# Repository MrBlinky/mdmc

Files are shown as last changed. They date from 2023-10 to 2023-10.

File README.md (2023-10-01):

# MDMC - Menu Driven Multi Cart

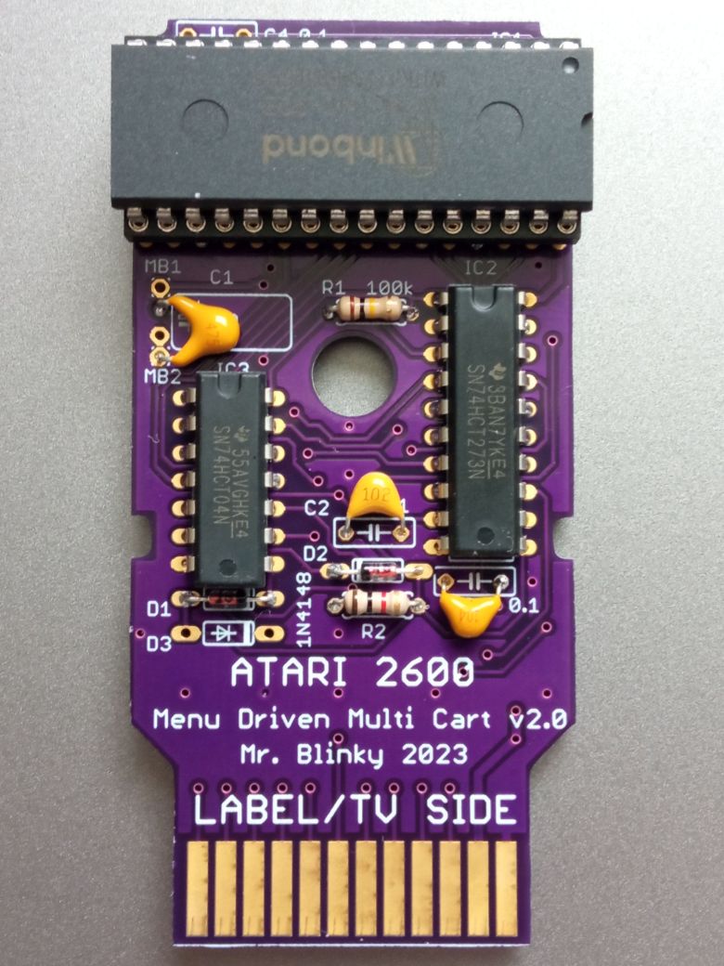
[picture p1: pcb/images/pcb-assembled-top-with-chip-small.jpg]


A Menu driven Multi Cart for the Atari 2600 made out of a few descrete logic chips and a (E)EPROM or FLASH memory.

Boards can be ordered from [OSH Park](https://oshpark.com/shared_projects/qgWffwwL) or you can create your own using the Eagle board file.

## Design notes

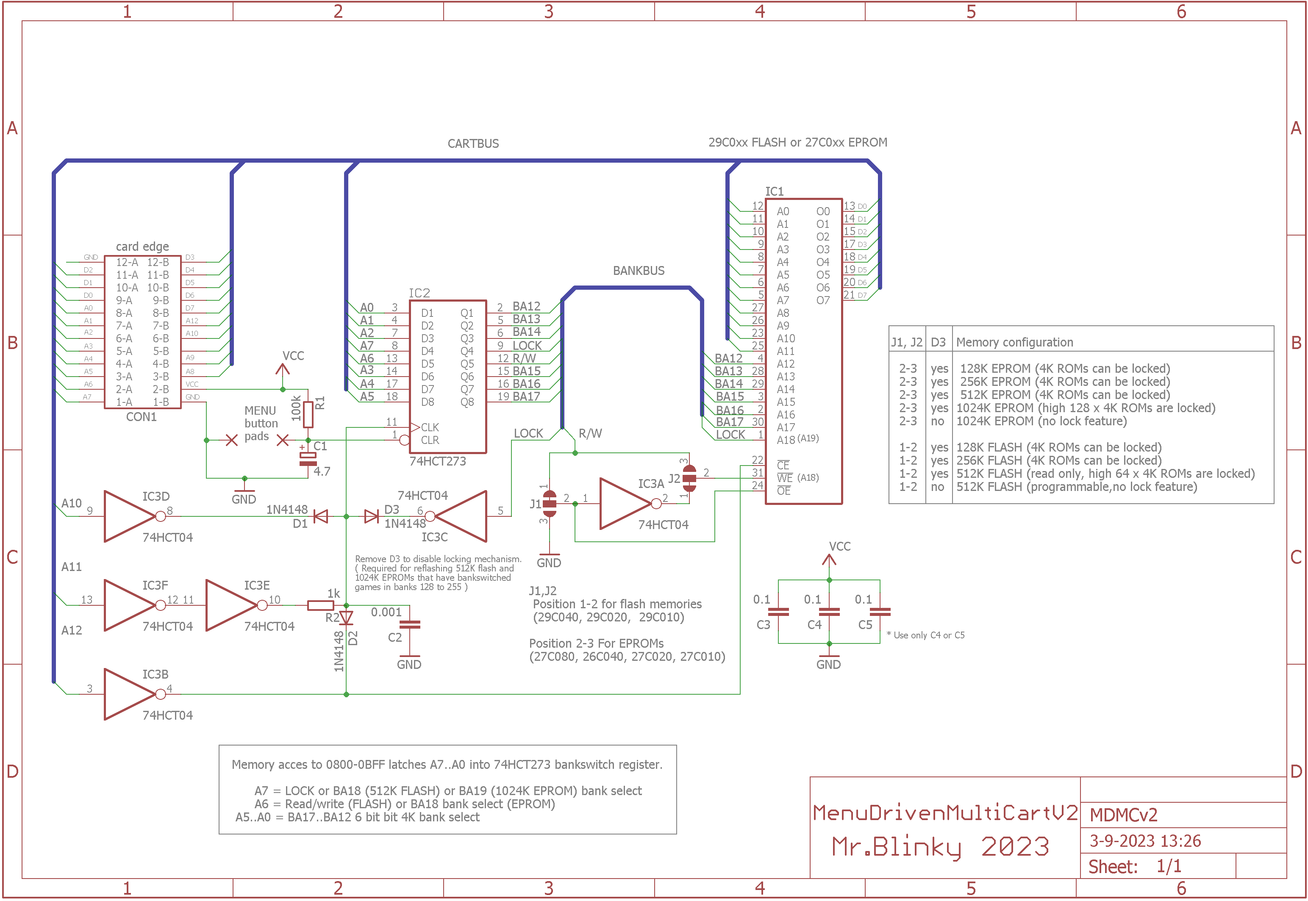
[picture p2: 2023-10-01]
pcb/eagle/MDMCv2-schematic.png

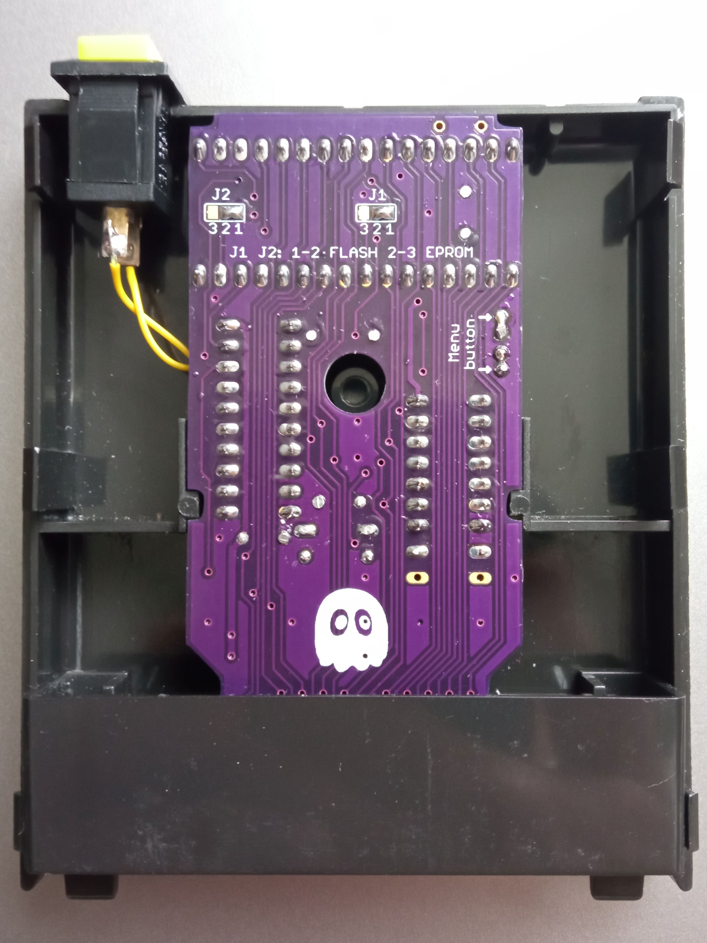
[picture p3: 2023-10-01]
pcb/images/pcb-inside-cart-with-switch.jpg

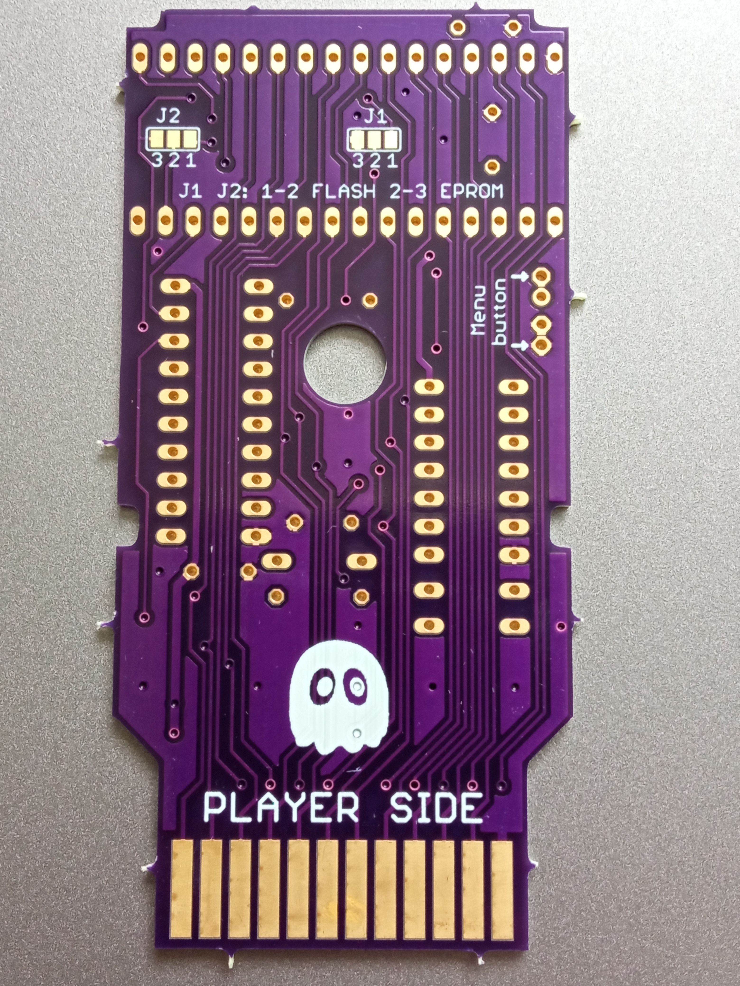
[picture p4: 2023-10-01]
pcb/images/pcb-raw-bottom.jpg

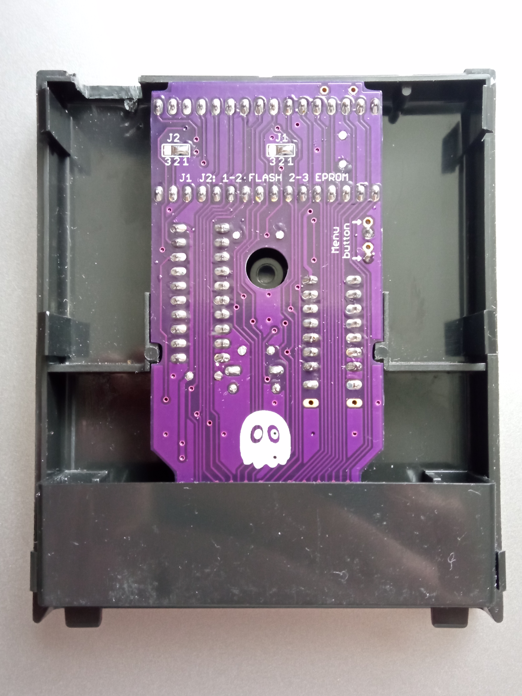
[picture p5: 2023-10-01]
pcb/images/pcb-inside-cart.jpg

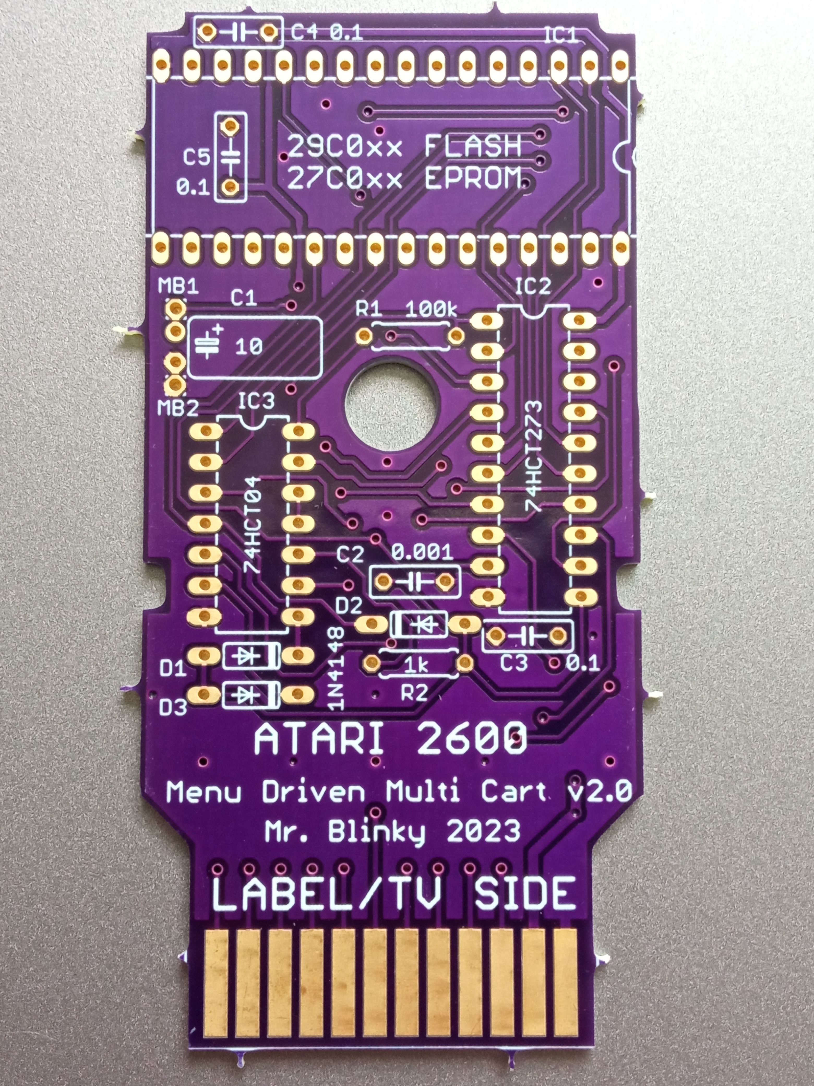
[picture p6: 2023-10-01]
pcb/images/pcb-raw-top.jpg

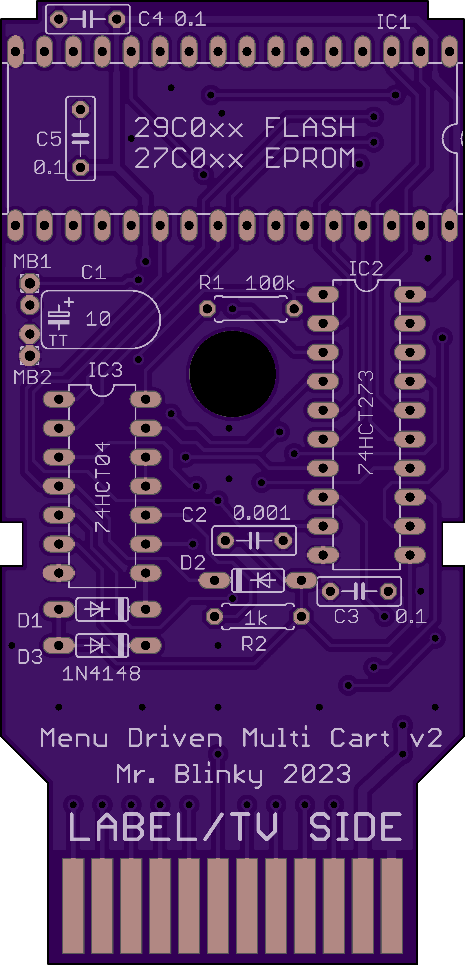
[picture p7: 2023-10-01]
pcb/images/pcb-oshpark-render-top.png

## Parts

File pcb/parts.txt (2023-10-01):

-----------------
MDMC v2 part list
-----------------

R1 = 100 kOhm
R2 = 1 kOhm

C1 = 4,7 uF (alternatives 1uF or 10uF)
C2 = 1 nF
C3, C4*, C5* = 100 nF

D1, D2, D3** = 1N4148

IC1 = EEPROM: 27C080, 27C040, 27C020, 27C010 or FLASH: 29C040, 29C020, 29C010
IC2 = 74HCT273 (alternatives 74HC273, 74LS273)
IC3 = 74HCT04 (alternatives  74HC04, 74LS04)

Optional:

32 pin IC socket
Garyma DS-429 momentary push button (for return to menu feature)

Notes:

*  Only solder C4 or C5.
   When soldering the EEPROM/FLASH chip directly on to the PCB, solder C4.
   When using an IC socket, solder C5.
   
** D3 required when bank locking feature is wanted for 4K roms that accidently may trigger bankswitch hotspots.
   D3 should not be used when bankswitch games are present in upper 512K of a 1MEG EPROM.
   D3 should not be used for 512K reprogrammable flash cart.

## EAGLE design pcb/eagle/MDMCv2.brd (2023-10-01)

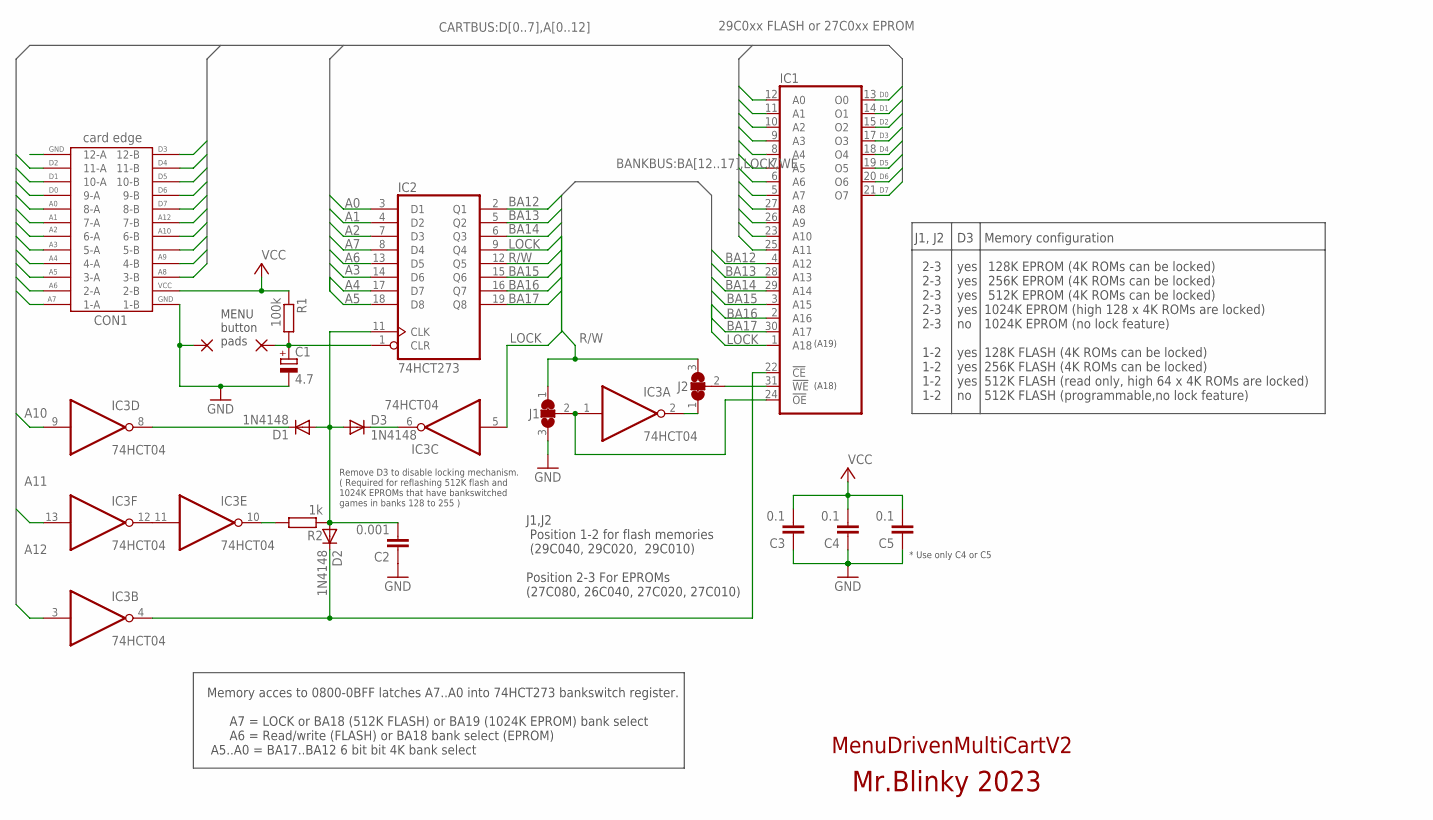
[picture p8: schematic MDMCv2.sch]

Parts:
C1: 4.7; TT2D5L
C2: 0.001; C050-025X075
C3, C4, C5: 0.1; C050-025X075
CON1: card edge; 24PINEDGE-254MM
D1, D2, D3: 1N4148; DO35-7
IC1: 29C0xx FLASH or 27C0xx EPROM; DIL32
IC2: 74HCT273; DIL20
IC3: 74HCT04; DIL14
J1, J2: SJ2W; SJ_2
MB1, MB2: WIREPAD1,6/0,9; 1,6/0,9
R1: 100k; 0207/7
R2: 1k; 0207/7

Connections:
!RESET: C1.+, IC2.1 (CLR), MB1.1, R1.2
/A10: D1.C, IC3.8 (O)
/A11: IC3.11 (I), IC3.12 (O)
/CE: D2.C, IC1.22 (!CE), IC3.4 (O)
/LOCK: D3.C, IC3.6 (O)
/OE: IC1.24 (!OE), IC3.1 (I), J1.2
/WE: IC1.31 (!WE), J2.2
/WEJ2: IC3.2 (O), J2.1
A0: CON1.8-A, IC1.12 (A0), IC2.3 (D1)
A1: CON1.7-A, IC1.11 (A1), IC2.4 (D2)
A2: CON1.6-A, IC1.10 (A2), IC2.7 (D3)
A3: CON1.5-A, IC1.9 (A3), IC2.14 (D6)
A4: CON1.4-A, IC1.8 (A4), IC2.17 (D7)
A5: CON1.3-A, IC1.7 (A5), IC2.18 (D8)
A6: CON1.2-A, IC1.6 (A6), IC2.13 (D5)
A7: CON1.1-A, IC1.5 (A7), IC2.8 (D4)
A8: CON1.3-B, IC1.27 (A8)
A9: CON1.4-B, IC1.26 (A9)
A10: CON1.6-B, IC1.23 (A10), IC3.9 (I)
A11: CON1.5-B, IC1.25 (A11), IC3.13 (I)
A11B: IC3.10 (O), R2.2
A12: CON1.7-B, IC3.3 (I)
BA12: IC1.4 (A12), IC2.2 (Q1)
BA13: IC1.28 (A13), IC2.5 (Q2)
BA14: IC1.29 (A14), IC2.6 (Q3)
BA15: IC1.3 (A15), IC2.15 (Q6)
BA16: IC1.2 (A16), IC2.16 (Q7)
BA17: IC1.30 (A17), IC2.19 (Q8)
CLK: C2.2, D1.A, D2.A, D3.A, IC2.11 (CLK), R2.1
D0: CON1.9-A, IC1.13 (O0)
D1: CON1.10-A, IC1.14 (O1)
D2: CON1.11-A, IC1.15 (O2)
D3: CON1.12-B, IC1.17 (O3)
D4: CON1.11-B, IC1.18 (O4)
D5: CON1.10-B, IC1.19 (O5)
D6: CON1.9-B, IC1.20 (O6)
D7: CON1.8-B, IC1.21 (O7)
GND: C1.-, C2.1, C3.1, C4.1, C5.1, CON1.1-B, CON1.12-A, IC1.16 (GND), IC2.10 (GND), IC3.7 (GND), J1.3, MB2.1
LOCK: IC1.1 (A18), IC2.9 (Q4), IC3.5 (I)
R/W: IC2.12 (Q5), J1.1, J2.3
VCC: C3.2, C4.2, C5.2, CON1.2-B, IC1.32 (VCC), IC2.20 (VCC), IC3.14 (VCC), R1.1

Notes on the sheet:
J1,J2 Position 1-2 for flash memories (29C040, 29C020, 29C010) Position 2-3 For EPROMs (27C080, 26C040, 27C020, 27C010)
MENU button pads
* Use only C4 or C5
Remove D3 to disable locking mechanism. ( Required for reflashing 512K flash and 1024K EPROMs that have bankswitched games in banks 128 to 255 )
MenuDrivenMultiCartV2
Mr.Blinky 2023
Memory acces to 0800-0BFF latches A7..A0 into 74HCT273 bankswitch register. A7 = LOCK or BA18 (512K FLASH) or BA19 (1024K EPROM) bank select A6 = Read/write (FLASH) or BA18 bank select (EPROM) A5..A0 = BA17..BA12 6 bit bit 4K bank select
(A18)
(A19)
Memory configuration 128K EPROM (4K ROMs can be locked) 256K EPROM (4K ROMs can be locked) 512K EPROM (4K ROMs can be locked) 1024K EPROM (high 128 x 4K ROMs are locked) 1024K EPROM (no lock feature) 128K FLASH (4K ROMs can be locked) 256K FLASH (4K ROMs can be locked) 512K FLASH (read only, high 6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
J1, J2 2-3 2-3 2-3 2-3 2-3 1-2 1-2 1-2 1-2
D3 yes yes yes yes no yes yes yes no

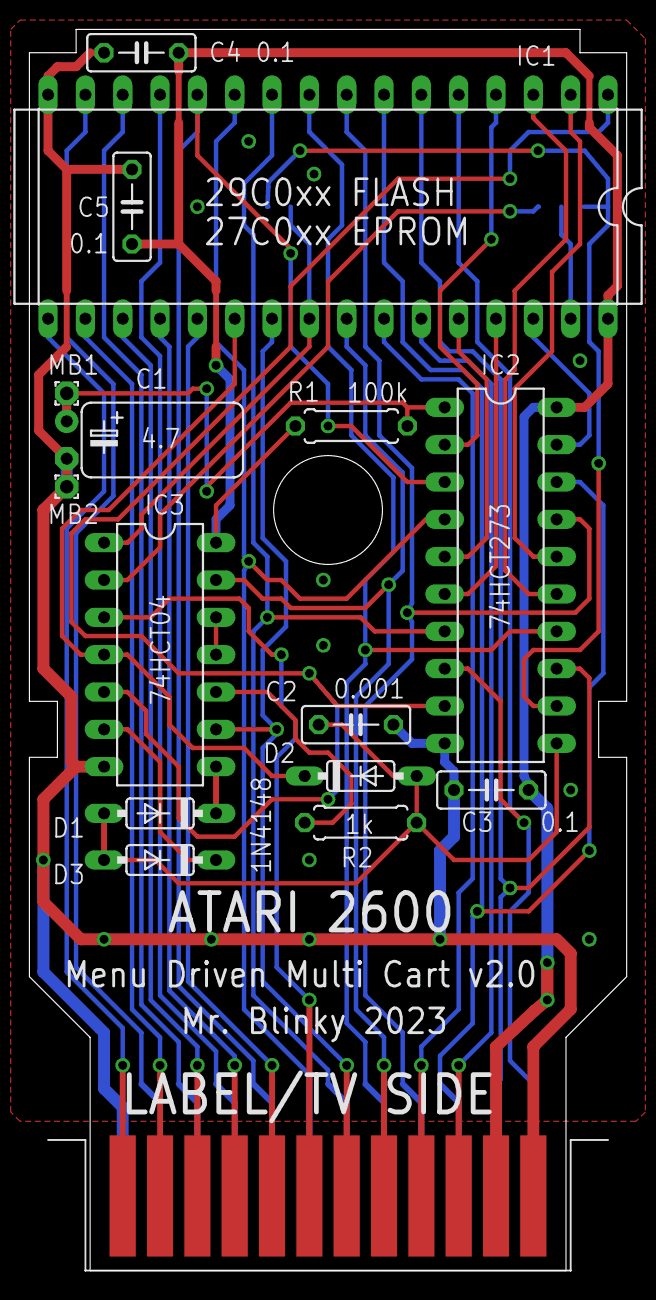
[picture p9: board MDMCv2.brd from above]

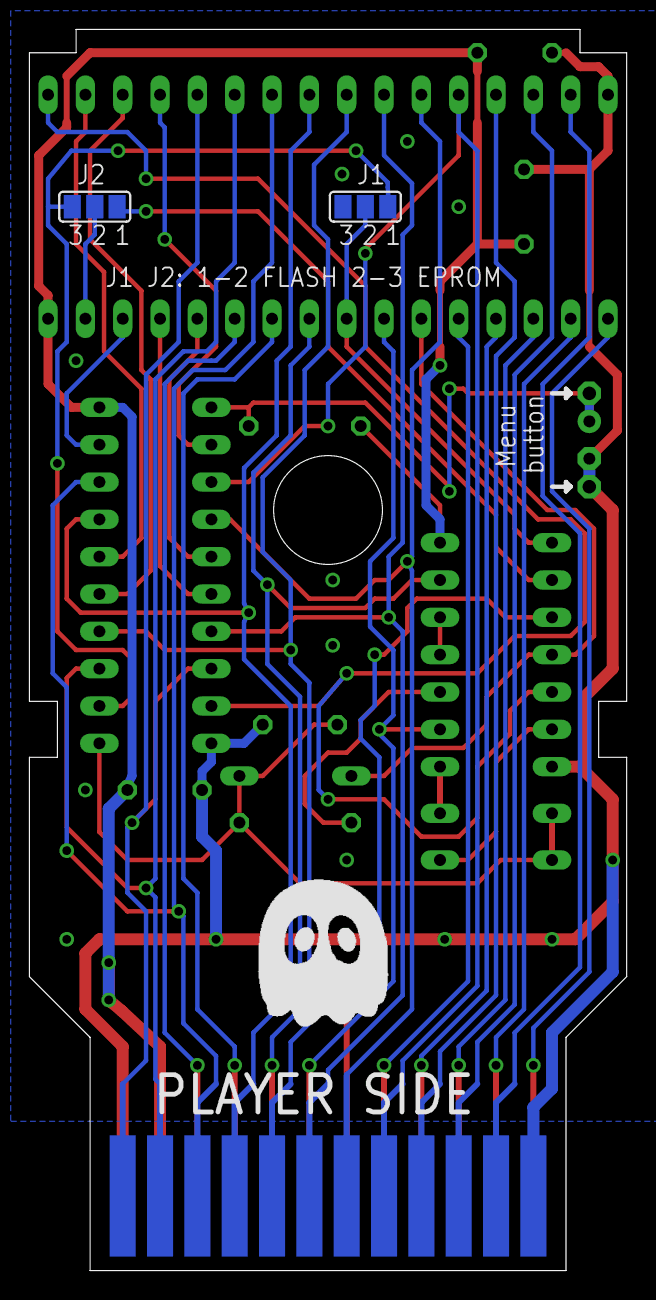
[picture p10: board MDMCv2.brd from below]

Board: 2 copper layers, 40.6 x 84.5 mm, 18 parts (3 on the bottom side), 41 nets.
